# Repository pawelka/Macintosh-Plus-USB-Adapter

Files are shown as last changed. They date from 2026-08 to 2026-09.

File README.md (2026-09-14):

# Macintosh Plus USB Keyboard and Mouse Adapter

Firmware for a CH554-based USB host adapter that lets a Macintosh Plus, 512K, or 128K use a modern USB HID keyboard and mouse.

The adapter enumerates a USB HID boot keyboard and/or boot mouse, translates keyboard reports to Macintosh keyboard protocol transitions, and converts USB mouse movement to Macintosh quadrature mouse signals.

## Current Status

This project is at working-prototype stage. A PCB is still TODO.

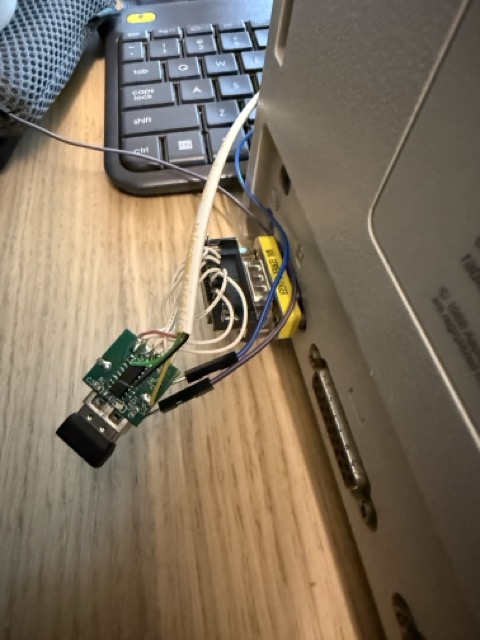
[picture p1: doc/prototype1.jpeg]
Prototype 1

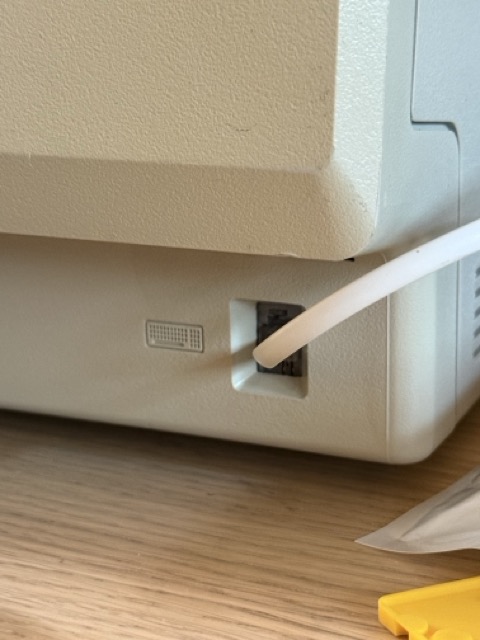
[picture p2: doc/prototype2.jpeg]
Prototype 2


## Supported Devices

- USB HID boot-protocol keyboards.
- USB HID boot-protocol mice.
- Composite keyboard/mouse receivers, such as many 2.4 GHz wireless dongles.
- A keyboard-only or mouse-only device.

The CH554 firmware handles one USB device on the root host port. If the keyboard and mouse are separate USB devices, use a combined receiver or build two adapters.

## Hardware Notes

The firmware targets a WCH CH554 running at 16 MHz.

Configured signal pins:

| DB9 pin| CH554 pin | Function |
| --- | --- | --- |
| N/A | P3.3 | Macintosh keyboard DATA |
| N/A | P3.4 | Macintosh keyboard CLOCK |
| 4 | P1.4 | Mouse X1 quadrature |
| 5 | P1.1 | Mouse X0 quadrature |
| 9 | P1.6 | Mouse Y0 quadrature |
| 8 | P1.7 | Mouse Y1 quadrature |
| 7 | P1.5 | Mouse button |
| N/A | P3.2 | USB/device status LED, active low |
| N/A | P3.1 | Optional UART0 TX debug output |
| N/A | P3.0 | Optional UART0 RX debug output |

Debug serial, when enabled, is UART0 TX on P3.1 at 9600 8N1.

## Building

Install PlatformIO, then install the project Python dependency into PlatformIO's Python environment.
On macOS or Linux:

```sh
~/.platformio/penv/bin/python -m pip install -r requirements-pio.txt
```

On Windows:

```powershell
& "$env:USERPROFILE\.platformio\penv\Scripts\python.exe" -m pip install -r requirements-pio.txt
```

Build the firmware:

```sh
pio run
```

## Flashing

The default upload command converts the Intel HEX output to `firmware.bin`, then flashes it with `ch55xtool.py`:

```sh
pio run -t upload
```

`ch55xtool.py` requires PyUSB and a native libusb backend. Both are provided by
the packages listed in `requirements-pio.txt`.

An alternate `wchisptool` upload command is kept in `platformio.ini` as a commented reference.

## Debug Logging

Serial debug logging is disabled by default:

```ini
-DDEBUG_SERIAL=0
```

To enable logs on UART0 TX P3.1 at 9600 8N1, change the build flag in `platformio.ini`:

```ini
-DDEBUG_SERIAL=1
```

## Credits

This project is inspired by [jjmz/Atari-Quadrature-USB-Mouse-Adapter](https://github.com/jjmz/Atari-Quadrature-USB-Mouse-Adapter). The mouse quadrature code and early CH554 programming references were derived from that project.

The USB host code is based on WCH CH554 examples, adapted for this adapter.

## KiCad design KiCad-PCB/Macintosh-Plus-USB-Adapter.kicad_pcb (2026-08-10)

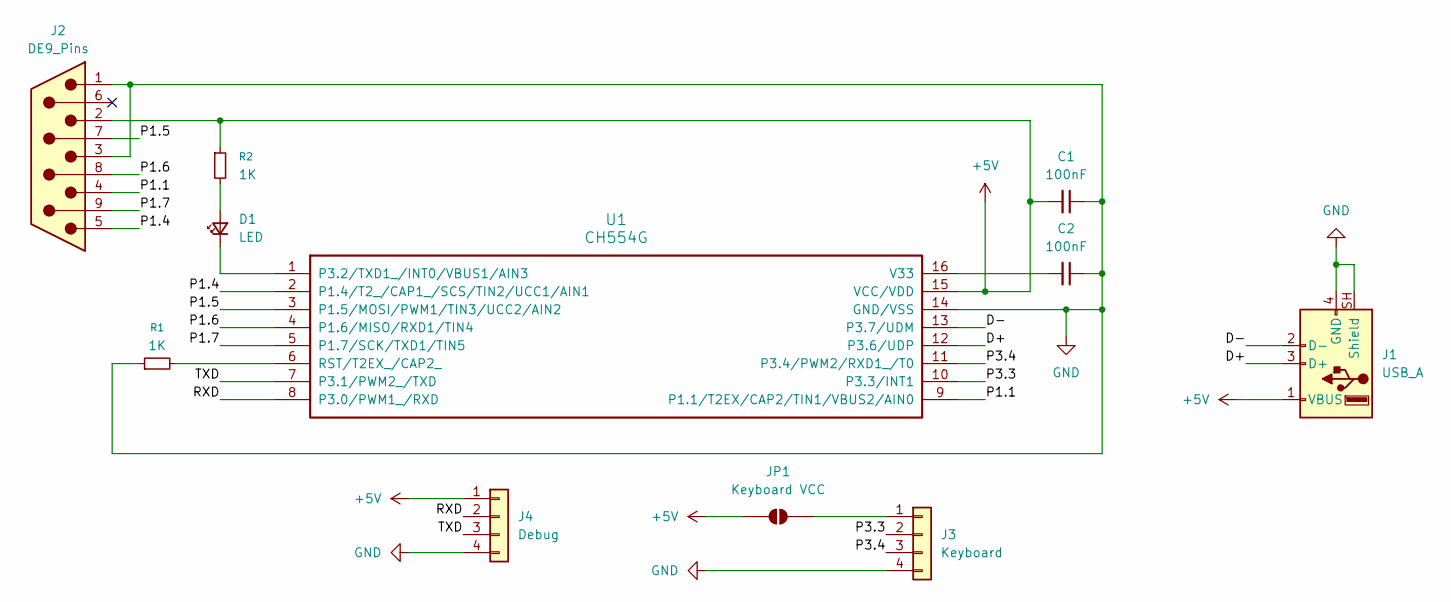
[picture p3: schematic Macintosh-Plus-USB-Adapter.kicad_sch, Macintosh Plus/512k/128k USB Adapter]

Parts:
C1, C2: 100nF; C_0805_2012Metric_Pad1.18x1.45mm_HandSolder
D1: LED; LED_0805_2012Metric
J1: USB_A; USB_A_TE_292303-7_Horizontal
J2: DE9_Pins; DSUB-9_Pins_EdgeMount_P2.77mm
J3: Keyboard; PinHeader_1x04_P1.00mm_Vertical
J4: Debug; PinHeader_1x04_P1.00mm_Vertical
JP1: Keyboard VCC; SolderJumper-2_P1.3mm_Open_Pad1.0x1.5mm
R1, R2: 1K; R_0805_2012Metric_Pad1.20x1.40mm_HandSolder
U1: CH554G; STC_SOP-16_3.9x9.9mm_P1.27mm

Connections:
+5V: C1.2, J1.1 (VBUS), J2.2, J4.1, JP1.1 (A), R2.1, U1.15 (VCC/VDD)
/D+: J1.3 (D+), U1.12 (P3.6/UDP)
/D-: J1.2 (D-), U1.13 (P3.7/UDM)
/P1.1: J2.4, U1.9 (P1.1/T2EX/CAP2/TIN1/VBUS2/AIN0)
/P1.4: J2.5, U1.2 (P1.4/T2_/CAP1_/SCS/TIN2/UCC1/AIN1)
/P1.5: J2.7, U1.3 (P1.5/MOSI/PWM1/TIN3/UCC2/AIN2)
/P1.6: J2.8, U1.4 (P1.6/MISO/RXD1/TIN4)
/P1.7: J2.9, U1.5 (P1.7/SCK/TXD1/TIN5)
/P3.3: J3.2, U1.10 (P3.3/INT1)
/P3.4: J3.3, U1.11 (P3.4/PWM2/RXD1_/T0)
/RXD: J4.2, U1.8 (P3.0/PWM1_/RXD)
/TXD: J4.3, U1.7 (P3.1/PWM2_/TXD)
GND: C1.1, C2.1, J1.4 (GND), J1.SH (Shield), J2.1, J2.3, J3.4, J4.4, R1.1, U1.14 (GND/VSS)
unnamed: D1.2 (A), R2.2
unnamed: D1.1 (K), U1.1 (P3.2/TXD1_/INT0/VBUS1/AIN3)
unnamed: J3.1, JP1.2 (B)
unnamed: R1.2, U1.6 (RST/T2EX_/CAP2_)
unnamed: C2.2, U1.16 (V33)

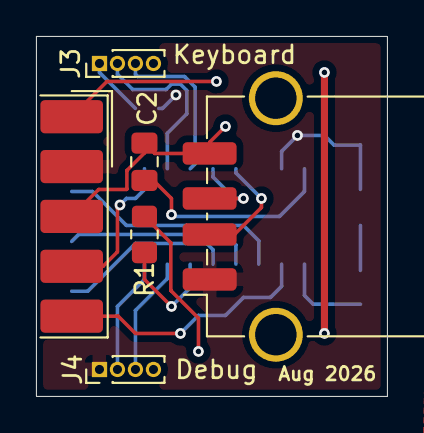
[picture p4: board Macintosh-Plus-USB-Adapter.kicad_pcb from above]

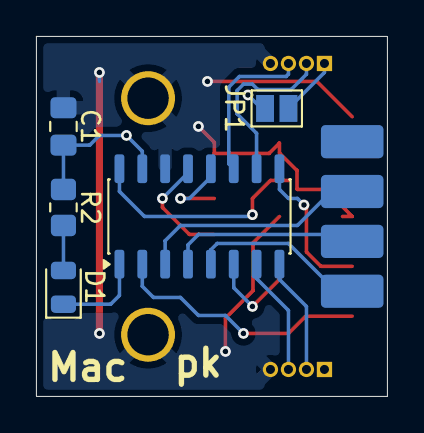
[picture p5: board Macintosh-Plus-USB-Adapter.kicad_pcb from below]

Board: 2 copper layers, 19.5 x 20.0 mm, 11 parts (5 on the bottom side), 18 nets.

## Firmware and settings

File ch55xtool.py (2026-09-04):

import sys, os
import time
import array
import math
import argparse

import usb.core
import usb.util
import usb.backend.libusb1
import libusb_package
        
#======= Some C-like static constants =======
DFU_ID_VENDOR = 0x4348
DFU_ID_PRODUCT = 0x55e0

EP_OUT_ADDR = 0x02
EP_IN_ADDR = 0x82

USB_MAX_TIMEOUT = 2000

DETECT_CHIP_CMD_V2 = [0xa1, 0x12, 0x00, 0x52, 0x11, 0x4d, 0x43, 0x55, 0x20, 0x49, 0x53,
				    0x50, 0x20, 0x26, 0x20, 0x57, 0x43, 0x48, 0x2e, 0x43, 0x4e]
END_FLASH_CMD_V2 = [0xa2, 0x01, 0x00, 0x00]
RESET_RUN_CMD_V2 = [0xa2, 0x01, 0x00, 0x01]
SEND_KEY_CMD_V20 = [0xa3, 0x30, 0x00]
SEND_KEY_CMD_V23 = [0xa3, 0x38, 0x00] + [0x00] * (0x38)
ERASE_CHIP_CMD_V2 = [0xa4, 0x01, 0x00, 0x08]
WRITE_CMD_V2 = [0xa5, 0x00, 0x00, 0x00, 0x00, 0x00, 0x00, 0x00]
VERIFY_CMD_V2 = [0xa6, 0x00, 0x00, 0x00, 0x00, 0x00, 0x00, 0x00]
READ_CFG_CMD_V2 = [0xa7, 0x02, 0x00, 0x1f, 0x00]

CH55X_IC_REF = {}
CH55X_IC_REF[0x51] = {'device_name': 'CH551', 'device_flash_size': 10240, 'device_dataflash_size': 128, 'chip_id': 0x51}
CH55X_IC_REF[0x52] = {'device_name': 'CH552', 'device_flash_size': 16384, 'device_dataflash_size': 128, 'chip_id': 0x52}
CH55X_IC_REF[0x53] = {'device_name': 'CH553', 'device_flash_size': 10240, 'device_dataflash_size': 128, 'chip_id': 0x53}
CH55X_IC_REF[0x54] = {'device_name': 'CH554', 'device_flash_size': 14336, 'device_dataflash_size': 128, 'chip_id': 0x54}
CH55X_IC_REF[0x59] = {'device_name': 'CH559', 'device_flash_size': 61440, 'device_dataflash_size': 128, 'chip_id': 0x59}
#=============================================

def __get_dfu_device(idVendor=DFU_ID_VENDOR, idProduct=DFU_ID_PRODUCT):
    backend = usb.backend.libusb1.get_backend(find_library=libusb_package.find_library)
    dev = usb.core.find(backend=backend, idVendor=idVendor, idProduct=idProduct)
    if dev is None:
        return (None, 'NO_DEV_FOUND')
    try:
        if dev.is_kernel_driver_active(0):
            try:
                dev.detach_kernel_driver(0)
            except usb.core.USBError:
                return (None, 'USB_ERROR_CANNOT_DETACH_KERNEL_DRIVER')
    except:
        pass #Windows dont need detach

    try:
        dev.set_configuration()
    except usb.core.USBError:
        return (None, 'USB_ERROR_CANNOT_SET_CONFIG')

    try:
        usb.util.claim_interface(dev, 0)
    except usb.core.USBError:
        return (None, 'USB_ERROR_CANNOT_CLAIM_INTERFACE')
    
    return (dev, '')

def __detect_ch55x_v2(dev):
    dev.write(EP_OUT_ADDR, DETECT_CHIP_CMD_V2)
    ret = dev.read(EP_IN_ADDR, 6, USB_MAX_TIMEOUT)
    try:
        return CH55X_IC_REF[ret[4]]
    except KeyError:
        return None

def __read_cfg_ch55x_v2(dev):
    dev.write(EP_OUT_ADDR, READ_CFG_CMD_V2)
    ret = dev.read(EP_IN_ADDR, 30, USB_MAX_TIMEOUT)

    ver_str = 'V%d.%d%d' % (ret[19], ret[20], ret[21])
    chk_sum = (ret[22] + ret[23] + ret[24] + ret[25]) % 256

    return (ver_str, chk_sum)

def __write_key_ch55x_v20(dev, chk_sum):
    SEND_KEY_CMD_V20 = SEND_KEY_CMD_V20 + [chk_sum] * 0x30

    dev.write(EP_OUT_ADDR, SEND_KEY_CMD_V20)
    ret = dev.read(EP_IN_ADDR, 6, USB_MAX_TIMEOUT)
    if ret[3] == 0: 
        return True
    else:
        return None

def __write_key_ch55x_v23(dev):
    dev.write(EP_OUT_ADDR, SEND_KEY_CMD_V23)
    ret = dev.read(EP_IN_ADDR, 6, USB_MAX_TIMEOUT)
    if ret[3] == 0: 
        return True
    else:
        return None

def __erase_chip_ch55x_v2(dev):
    dev.write(EP_OUT_ADDR, ERASE_CHIP_CMD_V2)
    ret = dev.read(EP_IN_ADDR, 6, USB_MAX_TIMEOUT)
    if ret[3] == 0: 
        return True
    else:
        return None

def __write_flash_ch55x_v20(dev, chk_sum, chip_id, payload):
    payload = payload + [0] * ((math.ceil(len(payload) / 56) * 56) - len(payload)) # Payload needs to be padded, 56 is a good number
    file_length = len(payload)

    for index in range(file_length):
        if index % 8 == 7:
            payload[index] = (payload[index] ^ ((chk_sum + chip_id) % 256)) % 256

    left_len = file_length
    curr_addr = 0

    while curr_addr < file_length:

        if left_len >= 56:
            pkt_length = 56
        else:
            pkt_length = left_len

        __WRITE_CMD_V2 = WRITE_CMD_V2
        __WRITE_CMD_V2[1] = pkt_length + 5
        __WRITE_CMD_V2[3] = curr_addr % 256
        __WRITE_CMD_V2[4] = (curr_addr >> 8) % 256
        __WRITE_CMD_V2[7] = left_len % 256
        __WRITE_CMD_V2 = __WRITE_CMD_V2 + payload[curr_addr:curr_addr+pkt_length]
        
        dev.write(EP_OUT_ADDR, __WRITE_CMD_V2)
        ret = dev.read(EP_IN_ADDR, 6, USB_MAX_TIMEOUT)

        curr_addr = curr_addr  + pkt_length
        left_len = left_len - pkt_length

        if ret[4] != 0x00:
            return None
        
    return file_length

def __write_flash_ch55x_v23(dev, chk_sum, chip_id, payload):
    payload = payload + [0] * ((math.ceil(len(payload) / 56) * 56) - len(payload)) # Payload needs to be padded, 56 is a good number
    file_length = len(payload)

    for index in range(file_length):
        if index % 8 == 7:
            payload[index] = (payload[index] ^ ((chk_sum + chip_id) % 256)) % 256
        else:
            payload[index] = (payload[index] ^ chk_sum) % 256

    left_len = file_length
    curr_addr = 0

    while curr_addr < file_length:

        if left_len >= 56:
            pkt_length = 56
        else:
            pkt_length = left_len

        __WRITE_CMD_V2 = WRITE_CMD_V2
        __WRITE_CMD_V2[1] = pkt_length + 5
        __WRITE_CMD_V2[3] = curr_addr % 256
        __WRITE_CMD_V2[4] = (curr_addr >> 8) % 256
        __WRITE_CMD_V2[7] = left_len % 256
        __WRITE_CMD_V2 = __WRITE_CMD_V2 + payload[curr_addr:curr_addr+pkt_length]
        
        dev.write(EP_OUT_ADDR, __WRITE_CMD_V2)
        ret = dev.read(EP_IN_ADDR, 6, USB_MAX_TIMEOUT)

        curr_addr = curr_addr  + pkt_length
        left_len = left_len - pkt_length

        if ret[4] != 0x00:
            return None
        
    return file_length

def __write_data_ch55x_v23(dev, chk_sum, chip_id, payload):
    payload = payload 
    file_length = len(payload)

    left_len = file_length
    curr_addr = 0

    while curr_addr < file_length:

        if left_len >= 56:
            pkt_length = 56
        else:
            pkt_length = left_len

        __WRITE_DF_V2 = WRITE_DF_V2
        __WRITE_DF_V2[1] = pkt_length 
        __WRITE_DF_V2[2] = curr_addr % 256
        __WRITE_DF_V2[3] = (curr_addr >> 8) % 256
        __WRITE_DF_V2 = __WRITE_DF_V2 + payload[curr_addr:curr_addr+pkt_length]
        
        dev.write(EP_OUT_ADDR, __WRITE_DF_V2)
        ret = dev.read(EP_IN_ADDR, 6, USB_MAX_TIMEOUT)

        curr_addr = curr_addr  + pkt_length
        left_len = left_len - pkt_length

        if ret[4] != 0x00:
            return None
        
    return file_length

def __verify_flash_ch55x_v20(dev, chk_sum, chip_id, payload):
    payload = payload + [0] * ((math.ceil(len(payload) / 56) * 56) - len(payload)) # Payload needs to be padded, 56 is a good number
    file_length = len(payload)

    for index in range(file_length):
        if index % 8 == 7:
            payload[index] = (payload[index] ^ ((chk_sum + chip_id) % 256)) % 256

    left_len = file_length
    curr_addr = 0

    while curr_addr < file_length:

        if left_len >= 56:
            pkt_length = 56
        else:
            pkt_length = left_len

        __VERIFY_CMD_V2 = VERIFY_CMD_V2
        __VERIFY_CMD_V2[1] = pkt_length + 5
        __VERIFY_CMD_V2[3] = curr_addr % 256
        __VERIFY_CMD_V2[4] = (curr_addr >> 8) % 256
        __VERIFY_CMD_V2[7] = left_len % 256
        __VERIFY_CMD_V2 = __VERIFY_CMD_V2 + payload[curr_addr:curr_addr+pkt_length]
        
        dev.write(EP_OUT_ADDR, __VERIFY_CMD_V2)
        ret = dev.read(EP_IN_ADDR, 6, USB_MAX_TIMEOUT)

        curr_addr = curr_addr  + pkt_length
        left_len = left_len - pkt_length

        if ret[4] != 0x00:
            return None
        
    return file_length

def __verify_flash_ch55x_v23(dev, chk_sum, chip_id, payload):
    payload = payload + [0] * ((math.ceil(len(payload) / 56) * 56) - len(payload)) # Payload needs to be padded, 56 is a good number
    file_length = len(payload)

    for index in range(file_length):
        if index % 8 == 7:
            payload[index] = (payload[index] ^ ((chk_sum + chip_id) % 256)) % 256
        else:
            payload[index] = (payload[index] ^ chk_sum) % 256

    left_len = file_length
    curr_addr = 0

    while curr_addr < file_length:

        if left_len >= 56:
            pkt_length = 56
        else:
            pkt_length = left_len

        __VERIFY_CMD_V2 = VERIFY_CMD_V2
        __VERIFY_CMD_V2[1] = pkt_length + 5
        __VERIFY_CMD_V2[3] = curr_addr % 256
        __VERIFY_CMD_V2[4] = (curr_addr >> 8) % 256
        __VERIFY_CMD_V2[7] = left_len % 256
        __VERIFY_CMD_V2 = __VERIFY_CMD_V2 + payload[curr_addr:curr_addr+pkt_length]
        
        dev.write(EP_OUT_ADDR, __VERIFY_CMD_V2)
        ret = dev.read(EP_IN_ADDR, 6, USB_MAX_TIMEOUT)

        curr_addr = curr_addr  + pkt_length
        left_len = left_len - pkt_length

        if ret[4] != 0x00:
            return None
        
    return file_length

def __end_flash_ch55x_v2(dev):
    dev.write(EP_OUT_ADDR, END_FLASH_CMD_V2)
    ret = dev.read(EP_IN_ADDR, 6, USB_MAX_TIMEOUT)
    if ret[4] != 0x00:
        return None
    else:
        return True

def __restart_run_ch55x_v2(dev):
    dev.write(EP_OUT_ADDR, RESET_RUN_CMD_V2)

def __main():
    parser = argparse.ArgumentParser(description="USBISP Tool For WinChipHead CH55x.")
    parser.add_argument('-f', '--file', type=str, default='', help="The target file to be flashed.")
    parser.add_argument('-d', '--data', type=str, default='', help="The target dataflash file to be flashed.")
    parser.add_argument('-r', '--reset_after_flash', action='store_true', default=False, help="Reset after finsh flash.")
    args = parser.parse_args()

    ret = __get_dfu_device()
    if ret[0] is None:
        sys.exit(ret[1])
    dev = ret[0]

    ret = __detect_ch55x_v2(dev)
    if ret is None:
        print('Unable to detect CH55x.')
    print('Found %s.' % ret['device_name'])
    chip_id = ret['chip_id']
    
    ret = __read_cfg_ch55x_v2(dev)
    chk_sum = ret[1]

    print('BTVER: %s.' % ret[0])

    if args.file != '':
        payload = list(open(args.file, 'rb').read())
        if ret[0] == 'V2.30':
            ret = __write_key_ch55x_v20(dev, chk_sum)
            if ret is None:
                sys.exit('Failed to write key to CH55x.')

            ret = __erase_chip_ch55x_v2(dev)
            if ret is None:
                sys.exit('Failed to erase CH55x.')
            
            ret = __write_flash_ch55x_v20(dev, chk_sum, chip_id, payload)
            if ret is None:
                sys.exit('Failed to flash firmware of CH55x.')

            ret = __verify_flash_ch55x_v20(dev, chk_sum, chip_id, payload)
            if ret is None:
                sys.exit('Failed to verify firmware of CH55x.')
        else: 
            if ret[0] == 'V2.31' or ret[0] == 'V2.40' or ret[0] == 'V2.50':
                ret = __write_key_ch55x_v23(dev)
                if ret is None:
                    sys.exit('Failed to write key to CH55x.')

                ret = __erase_chip_ch55x_v2(dev)
                if ret is None:
                    sys.exit('Failed to erase CH55x.')
                
                ret = __write_flash_ch55x_v23(dev, chk_sum, chip_id, payload)
                if ret is None:
                    sys.exit('Failed to flash firmware of CH55x.')

                ret = __verify_flash_ch55x_v23(dev, chk_sum, chip_id, payload)
                if ret is None:
                    sys.exit('Failed to verify firmware of CH55x.')
            else:
                sys.exit('Bootloader version not supported.')
        
        ret = __end_flash_ch55x_v2(dev)
        if ret is None:
            sys.exit('Failed to end flash process.')
        
        if args.data != '':
            payload = list(open(args.file, 'rb').read())
            ret = __write_data_ch55x_v23(dev, chk_sum, chip_id, payload)
            if ret is None:
                sys.exit('Failed to write Data to CH55x.')
        
        print('Flash done.')

        if args.reset_after_flash:
            __restart_run_ch55x_v2(dev)
            print('Restart and run.')



if __name__ == '__main__':
    __main()

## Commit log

2026-08-06 initial commit with working prototype
2026-08-10 KiCAD PCB design
    [Macintosh-Plus-USB-Adapter-B_Cu.gbr, Macintosh-Plus-USB-Adapter-B_Mask.gbr, Macintosh-Plus-USB-Adapter-B_Silkscreen.gbr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]
2026-09-04 introduce switch for keyboard <-> mouse priority, pcb + new pinout for pcb and remapping pins
